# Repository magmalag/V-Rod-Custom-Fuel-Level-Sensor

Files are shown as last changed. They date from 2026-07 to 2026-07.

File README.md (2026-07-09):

# V-Rod-Custom-Fuel-Level-Sensor
A custom DIY microcontroller-based (Arduino NANO Super Mini Atmega328) fuel level sensor for Harley-Davidson V-Rod. Replaces the unreliable factory ultrasonic sensor with a magnetic reed-switch array.

## The Problem
The OEM ultrasonic sensor is prone to failure due to vibrations, temperature changes, and piezo-element degradation. When it fails, the fuel gauge typically shows "Full" or drops to zero randomly.

## The Solution
This project replaces the ultrasonic unit with a highly reliable **magnetic reed-switch array**, processed by an **Atmega328 microcontroller**. It provides a perfectly stable analog signal (current sink) to the instrument cluster, perfectly mimicking a working OEM sensor.

### Hardware Features
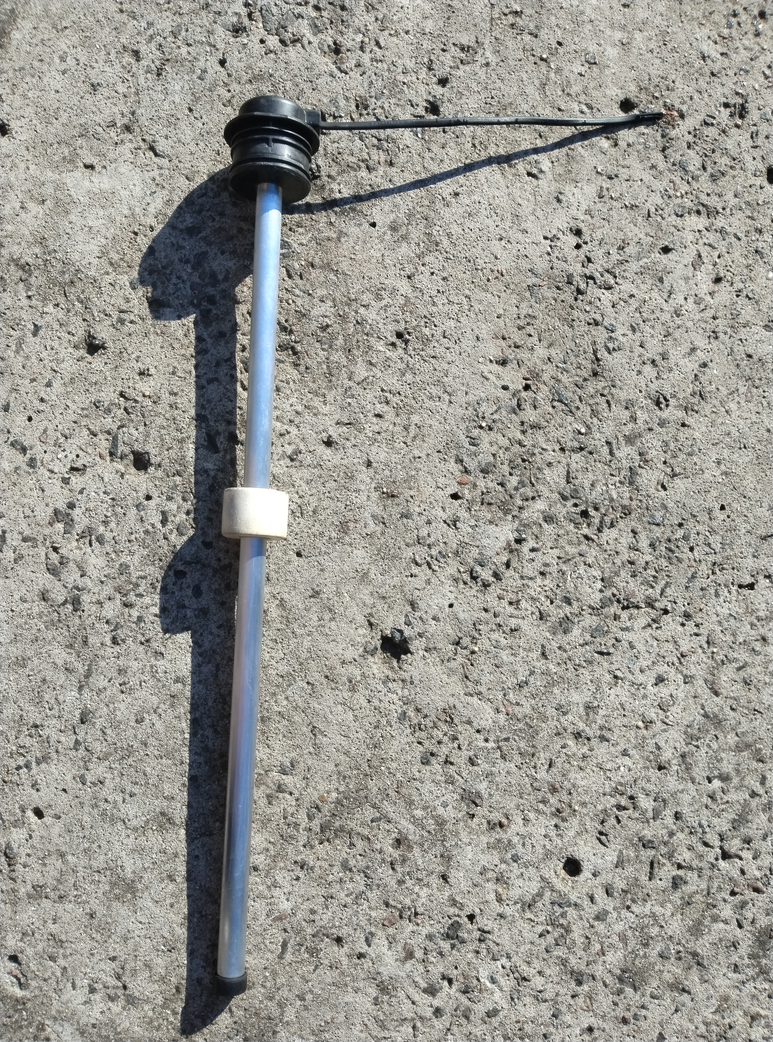
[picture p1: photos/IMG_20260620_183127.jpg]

- **Sensor Probe:** Aluminum tube housing an array of 40 reed switches and resistors.
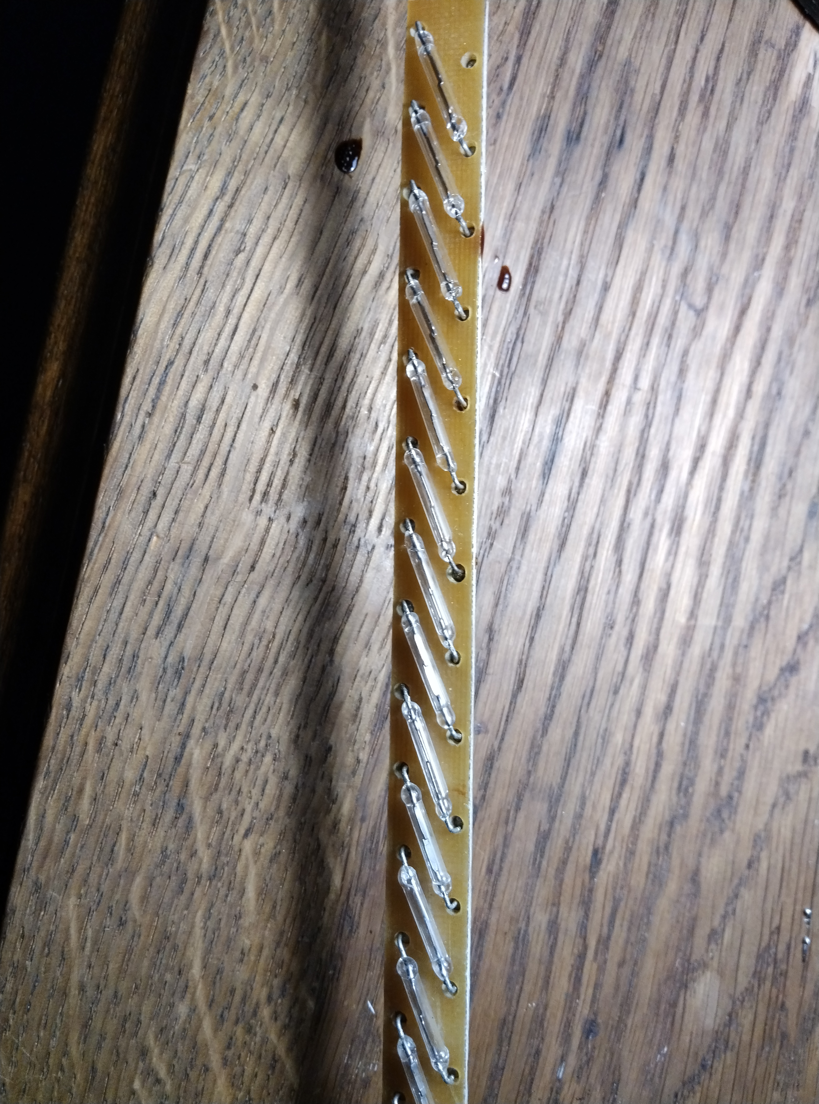
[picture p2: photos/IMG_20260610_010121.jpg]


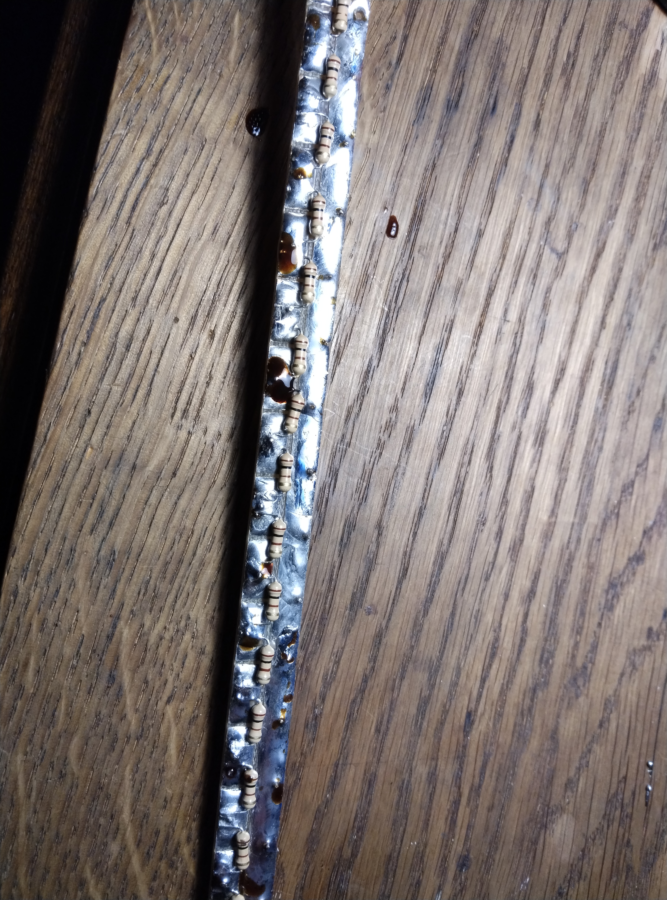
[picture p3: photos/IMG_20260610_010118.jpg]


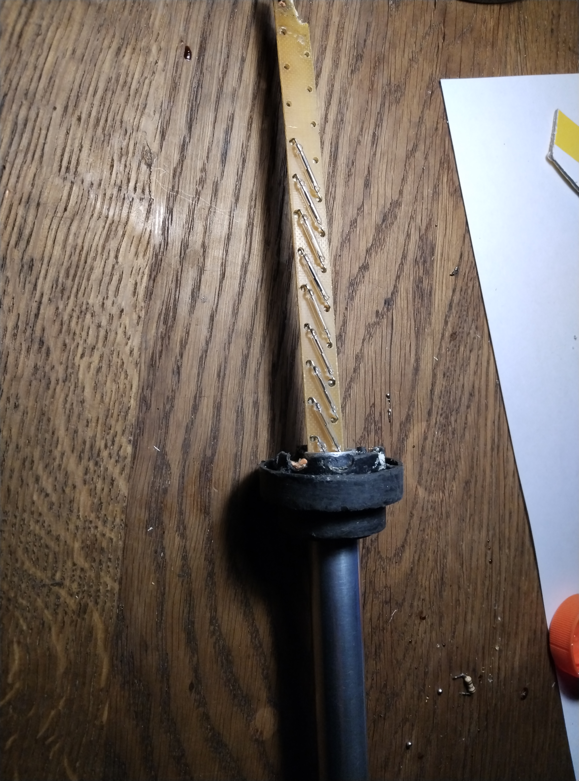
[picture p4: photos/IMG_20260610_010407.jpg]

- **The Float (PVC-2-195):** The float is custom-machined from **ПХВ-2-195 (PVC-2-195)** — an aviation-grade, closed-cell polyvinyl chloride foam. Unlike regular plastics or foams, it is 100% resistant to high-octane gasoline and ethanol blends, never absorbs fuel, and securely holds the dual neodymium magnets.
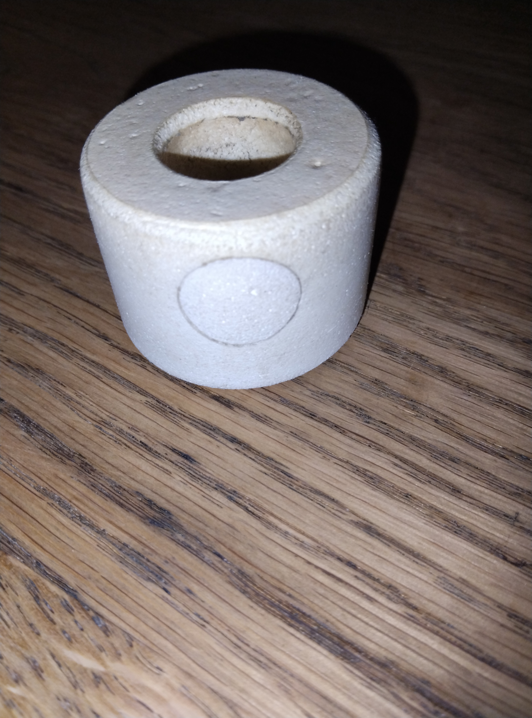
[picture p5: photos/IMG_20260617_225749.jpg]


- **Microcontroller:** Arduino NANO Super Mini Atmega328.

- **The Active Feedback Loop (LM358 + AO3400A):** 
This is the heart of the hardware. Simply using a PWM-driven transistor to ground the signal wire causes gauge needle bounce due to alternator voltage spikes (ranging from 12.5V at idle to 14.4V while riding). To solve this, the project utilizes a combination of a hardware constant current sink and dynamic software compensation:

1. **Hardware Constant Current Sink:** The Arduino Nano outputs a high-frequency PWM signal, which is smoothed into a stable DC reference voltage using an RC filter. This reference voltage is fed into the non-inverting input of the LM358 operational amplifier. Operating in a closed-loop feedback configuration with the AO3400A N-channel MOSFET and a source sense resistor, the LM358 continuously regulates the MOSFET's gate voltage. This ensures a precise, steady current draw (ranging from 12 mA to 20 mA) from the instrument cluster, shielding the signal from rapid electrical noise on the line.

2. **Dynamic Voltage Compensation:** Although the constant current sink stabilizes the output, fluctuations in the motorcycle's overall system voltage (12.5V to 14.4V) can still slightly affect the cluster's internal current-sensing behavior. To address this, the Arduino Nano monitors the system voltage via a resistor voltage divider connected to an analog pin. The firmware measures this voltage in real-time and dynamically adjusts the PWM duty cycle to compensate for these system-wide variations, keeping the gauge needle stable and consistent under all riding conditions.

## Tank Calibration
The V-Rod fuel tank has a complex, irregular shape. To ensure absolute accuracy (including the "Miles to Empty" range calculator), the sensor was mapped by filling the tank liter by liter with actual fuel.

## Schematic & PCB
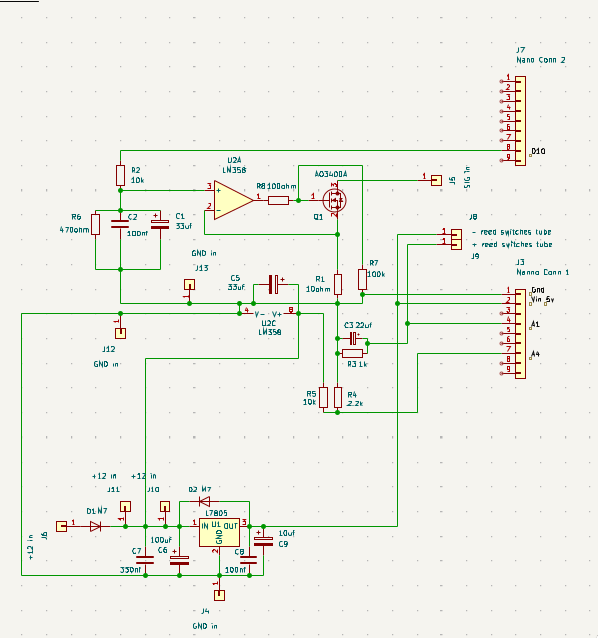
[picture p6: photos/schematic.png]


## Source Code
Developed for the Harley-Davidson V-Rod, which has a complex-shaped under-seat fuel tank causing standard sensors to read highly non-linearly.

This code converts the non-linear resistance signal from the fuel float into a perfectly smooth PWM signal for an analog gauge, distributing the fuel volume evenly across the gauge marks (Empty, 1/4, 1/2, 3/4, Full).

## 🚀 Features
* **Anti-Slosh Logic:** Dual signal filtering (Median filter + Smoothing/Low-pass filter). The needle won't jump during braking, acceleration, or cornering.
* **Custom Tank Calibration:** A 33-point lookup table allows perfect volume mapping for a fuel tank of any geometric shape.
* **System Voltage Compensation:** Sensor readings remain accurate even during voltage drops (e.g., turning on headlights or radiator fans), as the Arduino monitors the battery voltage and dynamically compensates the PWM output.
* **Gauge Calibration Mode:** Built-in `CALIBRATION_MODE` to quickly find the exact PWM values needed for your specific aftermarket gauge.

## 🛠 Hardware & Wiring
* **Microcontroller:** Arduino Nano / Pro Mini (or any compatible board).
* **Sensor Input:** `A1` *(A pull-up resistor is required depending on your specific sender's resistance).*
* **Battery Voltage Monitor:** `A4` ⚠️ **WARNING:** Must be connected via a voltage divider! Motorcycle system voltage can reach 14.5V+, which will fry the Arduino pin if connected directly.
* **Gauge Output:** `D10` *(PWM output to the gauge).*

## 📐 Calibration Guide

If you are adapting this project for a different motorcycle or fuel tank, you need to complete a 2-step calibration process:

### Step 1: Gauge Needle Calibration
1. Set `bool CALIBRATION_MODE = true;` at the beginning of the code.
2. Change the `TEST_PWM` value, upload the code, and observe where the needle stops on the gauge.
3. Find the exact PWM values for your gauge marks (Empty, 1/4, 1/2, 3/4, Full) and write them into the `gPWM[]` array.
4. In the `gLiters[]` array, define how many liters each mark represents (e.g., for a 20.5L tank, the step for each 1/8 increment would be 2.5L).

### Step 2: Fuel Tank Mapping
1. Set `CALIBRATION_MODE = false;`.
2. Completely drain the fuel tank. Open the Arduino IDE Serial Monitor at 115200 baud.
3. Record the `Raw_Sensor` value for the empty tank.
4. Pour fuel into the tank in small, measured portions (e.g., 1 liter at a time) and record the `Raw_Sensor` readings for each step.
5. Transfer these "ADC - Liters" pairs into the `rawTable[]` and `litersTable[]` arrays. 
*Important: The arrays must be strictly ascending, with no duplicate ADC values in a row!*

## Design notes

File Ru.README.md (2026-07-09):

# V-Rod-Custom-Fuel-Level-Sensor

Самодельный датчик уровня топлива на базе микроконтроллера (Arduino NANO Super Mini Atmega328) для мотоцикла Harley-Davidson V-Rod. Заменяет ненадежный заводской ультразвуковой датчик на плату с магнитными герконами.

## Проблема

Заводской ультразвуковой датчик (OEM) часто выходит из строя из-за сильных вибраций, резких перепадов температур и постепенной деградации пьезоэлемента. При его поломке стрелка указателя топлива на приборной панели обычно зависает на отметке «Полный» или хаотично падает на ноль.

## Решение

В данном проекте ультразвуковой датчик заменен надежным **зондом на основе герконов и магнита**, показания с которого обрабатываются микроконтроллером **Atmega328**. Устройство формирует стабильный аналоговый сигнал (управление током) для приборной панели, полностью имитируя работу исправного заводского датчика.

### Аппаратные особенности



- **Измерительный зонд:** Алюминиевая трубка, внутри которой размещена плата с 40 герконами и резисторами.







- **Поплавок (ПХВ-2-195):** Изготовлен на станке из авиационного закрытоячеистого пенополивинилхлорида **ПХВ-2-195**. В отличие от обычных пластиков или строительной пены, данный материал на 100% устойчив к высокооктановому бензину и смесям с этанолом, никогда не впитывает топливо и надежно удерживает два неодимовых магнита внутри своей конструкции.



- **Микроконтроллер:** Arduino NANO Super Mini Atmega328.
- **Активный контур обратной связи (LM358 + AO3400A):**  
  Это ключевой узел аппаратной части устройства. Простое использование транзистора с ШИМ-управлением для замыкания сигнального провода приборки на массу приводило бы к сильным колебаниям стрелки из-за скачков напряжения генератора (от 12.5 В на холостом ходу до 14.4 В при езде). Чтобы исключить это влияние, в проекте используется сочетание аппаратного источника стабильного тока и динамической программной компенсации:

  1. **Аппаратный источник стабильного тока:** Arduino Nano выдает высокочастотный ШИМ-сигнал, который сглаживается RC-фильтром в стабильное постоянное опорное напряжение. Это опорное напряжение подается на неинвертирующий вход операционного усилителя LM358. Работая в замкнутом контуре обратной связи с N-канальным MOSFET-транзистором AO3400A и шунтом в цепи истока, LM358 непрерывно регулирует напряжение на затворе транзистора. Это обеспечивает точное и стабильное потребление тока (в диапазоне от 12 мА до 20 мА) от приборной панели, защищая сигнал от быстрых электрических помех в бортовой сети.
  2. **Динамическая компенсация напряжения:** Несмотря на то, что источник стабильного тока сглаживает выходной сигнал, колебания общего напряжения мотоцикла (с 12.5 В до 14.4 В) все же могут незначительно влиять на логику измерения тока внутри самой приборной панели. Для устранения этого эффекта Arduino Nano отслеживает системное напряжение через резистивный делитель, подключенный к аналоговому пину. Микропрограмма измеряет это напряжение в реальном времени и динамически корректирует скважность ШИМ, компенсируя просадки сети и удерживая стрелку в стабильном положении при любых режимах езды.

## Калибровка бака

Топливный бак V-Rod имеет сложную неправильную геометрию. Чтобы обеспечить высокую точность показаний (включая правильный расчет запаса хода «Miles to Empty» в бортовом компьютере), датчик калибровался путем пошагового заполнения бака реальным топливом — буквально литр за литром.

## Схема и печатная плата (PCB)



## Исходный код (Source Code)

Разработано специально для мотоциклов Harley-Davidson V-Rod, под сиденьем которых расположен бак сложной формы, из-за чего стандартные датчики уровня выдают крайне нелинейные показания.

Этот код преобразует нелинейный сигнал сопротивления от датчика-поплавка в плавный ШИМ-сигнал для аналогового указателя, равномерно распределяя объем топлива по меткам шкалы приборной панели (Пусто, 1/4, 1/2, 3/4, Полный).

## 🚀 Особенности (Features)

- **Алгоритм защиты от плескания (Anti-Slosh):** Двойная фильтрация сигнала (медианный фильтр + сглаживающий фильтр низких частот). Стрелка прибора не дергается при резком торможении, ускорении или в затяжных поворотах.
- **Индивидуальная калибровка бака:** Таблица поиска на 33 точки позволяет точно сопоставить объем бака любой геометрической формы с показаниями датчика.
- **Компенсация напряжения сети:** Показания датчика остаются точными даже при просадках напряжения (например, при включении головного света или вентиляторов радиатора), так как Arduino непрерывно контролирует вольтаж батареи и на лету корректирует ШИМ.
- **Режим калибровки шкалы:** Встроенный режим `CALIBRATION_MODE` позволяет быстро подобрать точные значения ШИМ под конкретный неоригинальный (aftermarket) указатель.

## 🛠 Аппаратная часть и подключение (Hardware & Wiring)

- **Микроконтроллер:** Arduino Nano / Pro Mini (или любая совместимая плата).
- **Вход датчика:** `A1` *(требуется подтягивающий резистор, номинал которого зависит от сопротивления вашего датчика).*
- **Мониторинг напряжения батареи:** `A4` ⚠️ **ВНИМАНИЕ:** Подключать строго через делитель напряжения! Напряжение в сети мотоцикла может превышать 14.5 В, что сожжет аналоговый пин Arduino при прямом подключении.
- **Выход на приборную панель:** `D10` *(ШИМ-выход на указатель).*

## 📐 Руководство по калибровке (Calibration Guide)

Если вы адаптируете этот проект под другой мотоцикл или бак, вам необходимо пройти процесс калибровки, состоящий из 2 шагов:

### Шаг 1: Калибровка положения стрелки прибора

1. Установите `bool CALIBRATION_MODE = true;` в начале кода.
2. Изменяйте значение переменной `TEST_PWM`, прошивайте плату и наблюдайте, на какой отметке шкалы останавливается стрелка приборной панели.
3. Найдите точные значения ШИМ для каждой отметки шкалы (Пусто, 1/4, 1/2, 3/4, Полный) и запишите их в массив `gPWM[]`.
4. В массиве `gLiters[]` укажите, какому объему в литрах соответствует каждая риска (например, для бака объемом 20.5 л шаг для каждого деления в 1/8 шкалы составит примерно 2.5 л).

### Шаг 2: Градуировка топливного бака

1. Установите `CALIBRATION_MODE = false;`.
2. Полностью слейте топливо из бака. Откройте монитор порта в Arduino IDE на скорости 115200 бод.
3. Запишите значение `Raw_Sensor` для пустого бака.
4. Наливайте топливо в бак небольшими точными порциями (например, по 1 литру) и фиксируйте показания `Raw_Sensor` на каждом шаге.
5. Перенесите полученные пары «АЦП — Литры» в массивы `rawTable[]` и `litersTable[]`.  
   *Важно: значения в массивах должны идти строго по возрастанию, без дублирования одинаковых значений АЦП подряд!*

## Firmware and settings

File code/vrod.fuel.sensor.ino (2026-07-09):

#include <avr/pgmspace.h>

// ==================== РЕЖИМ НАСТРОЙКИ ПРИБОРКИ ====================
bool CALIBRATION_MODE = false;  // true - ручной подбор ШИМ, false - работа от датчика
int  TEST_PWM = 183;            // МЕНЯЙ ЭТО ЧИСЛО, чтобы двигать стрелку по рискам

// ==================== НАСТРОЙКА РИСОК ПРИБОРКИ ====================
const int G_POINTS = 9;        
const int gPWM[] = {
  183, // ШИМ для риски 0 (Пусто)
  189, // ШИМ для риски 1/8
  196, // ШИМ для риски 1/4
  203, // ШИМ для риски 3/8
  210, // ШИМ для риски 1/2 (Половина)
  216, // ШИМ для риски 5/8
  222, // ШИМ для риски 3/4
  227, // ШИМ для риски 7/8
  232  // ШИМ для риски 1/1 (Полный)
};

// Литры, соответствующие рискам на приборке
const float gLiters[] = {0, 2.5, 5.0, 7.5, 10.0, 12.5, 15.0, 17.5, 20.5}; 

// ==================== ПИНЫ И ЖЕЛЕЗО ====================
const int sensorPin = A1;  
const int batteryPin = A4; 
const int outputPin = 10;   

const int PWM_OFFSET = -32;  
const int SYS_REF = 455;     
const float COMP_FACTOR = 0.40; 
const int USE_VOLTAGE_COMP = 1;
const float FUEL_FILTER_K = 0.08; 

// ==================== ТВОЯ ИДЕАЛЬНАЯ ТАБЛИЦА (С ЛИСТОЧКА) ====================
// Всего 33 точки. Я перенес каждую цифру с твоей фотографии!
const int NUM_POINTS = 33;  

const int rawTable[] PROGMEM = { 
  222, 226, 237, 242, 248, 253, 260, 268, 272, 280, 
  287, 295, 305, 330, 341, 352, 365, 376, 390, 420, 
  437, 454, 496, 520, 545, 605, 642, 681, 726, 777, 
  837, 987, 1023 
};

const float litersTable[] PROGMEM = { 
  0.0,  2.0,  3.4,  4.0,  5.0,  5.7,  6.2,  7.0,  7.5,  8.3, 
  9.0,  9.4,  10.0, 11.0, 11.3, 11.7, 12.0, 12.2, 12.5, 13.2, 
  13.6, 13.8, 14.0, 14.4, 15.0, 16.1, 17.0, 17.4, 18.0, 18.7, 
  19.3, 20.1, 20.5 
};

float filteredInput = 0;

// ==================== ФУНКЦИИ ====================

// Медианный фильтр (отсекает резкие всплески от плескания бензина)
int getMedianRead(int pin) {
  int samples[5];
  for (int i = 0; i < 5; i++) samples[i] = analogRead(pin);
  for (int i = 0; i < 4; i++) {
    for (int j = i + 1; j < 5; j++) {
      if (samples[i] > samples[j]) {
        int temp = samples[i]; samples[i] = samples[j]; samples[j] = temp;
      }
    }
  }
  return samples[2]; 
}

// Преобразование "попугаев" АЦП в литры по твоей таблице
float getLitersFromRaw(int raw) {
  if (raw <= pgm_read_word(&rawTable[0])) return pgm_read_float(&litersTable[0]);
  if (raw >= pgm_read_word(&rawTable[NUM_POINTS-1])) return pgm_read_float(&litersTable[NUM_POINTS-1]);
  for (int i = 0; i < NUM_POINTS-1; i++) {
    int r1 = pgm_read_word(&rawTable[i]);
    int r2 = pgm_read_word(&rawTable[i+1]);
    if (raw >= r1 && raw <= r2) {
      float l1 = pgm_read_float(&litersTable[i]);
      float l2 = pgm_read_float(&litersTable[i+1]);
      return l1 + (float)(raw - r1) / (r2 - r1) * (l2 - l1);
    }
  }
  return pgm_read_float(&litersTable[NUM_POINTS-1]);
}

// Преобразование литров в ШИМ для приборки
int getPwmForLiters(float liters) {
  if (liters <= gLiters[0]) return gPWM[0];
  if (liters >= gLiters[G_POINTS-1]) return gPWM[G_POINTS-1];
  for (int i = 0; i < G_POINTS-1; i++) {
    if (liters >= gLiters[i] && liters <= gLiters[i+1]) {
      float ratio = (liters - gLiters[i]) / (gLiters[i+1] - gLiters[i]);
      return gPWM[i] + (int)(ratio * (gPWM[i+1] - gPWM[i]));
    }
  }
  return gPWM[G_POINTS-1];
}

// ==================== ИНИЦИАЛИЗАЦИЯ ====================
void setup() {
  Serial.begin(115200);
  pinMode(outputPin, OUTPUT);
  
  // При включении зажигания мгновенно считываем уровень топлива,
  // чтобы стрелка сразу встала куда нужно, а не ползла медленно с нуля.
  filteredInput = getMedianRead(sensorPin); 
}

// ==================== ОСНОВНОЙ ЦИКЛ ====================
void loop() {
  // 1. Мгновенный вольтметр
  int currentBattery = getMedianRead(batteryPin);

  // 2. Чтение датчика топлива (чистые данные)
  int rawInput = getMedianRead(sensorPin);
  
  // Плавный фильтр: стрелка не будет дергаться в поворотах
  filteredInput += (float)(rawInput - filteredInput) * FUEL_FILTER_K;   
  float currentLiters = getLitersFromRaw((int)filteredInput);

  // 3. Выбор режима ШИМ
  int currentPwm;
  if (CALIBRATION_MODE) {
    currentPwm = TEST_PWM; // Ручной подбор ШИМ (если true)
  } else {
    currentPwm = getPwmForLiters(currentLiters); // Автоматический расчет по таблице
  }

  // 4. Компенсация вольтажа бортсети (чтобы приборка не врала при просадках напряжения)
  if (USE_VOLTAGE_COMP == 1) {
    float sysDelta = (float)currentBattery - (float)SYS_REF; 
    currentPwm = currentPwm + (int)(sysDelta * COMP_FACTOR); 
  }

  // Применяем офсет (калибровку самой приборки) и выдаем на ножку
  int finalOutput = constrain(currentPwm + PWM_OFFSET, 120, 254);
  analogWrite(outputPin, finalOutput);

  // 5. Вывод в монитор порта (каждые 200мс)
  static uint32_t timer = 0;
  if (millis() - timer > 200) {
    timer = millis();
    Serial.print(F("Raw_Sensor:")); Serial.print(rawInput);
    Serial.print(F(" | Liters:")); Serial.print(currentLiters, 1);
    
    if (CALIBRATION_MODE) {
      Serial.print(F(" | TEST_PWM:")); Serial.print(TEST_PWM);
    } else {
      Serial.print(F(" | BASE_PWM:")); Serial.print(currentPwm);
    }
    
    Serial.print(F(" | BatRaw:")); Serial.print(currentBattery);
    Serial.print(F(" | FINAL_PWM:")); Serial.println(finalOutput);
  }
  delay(10); 
}
